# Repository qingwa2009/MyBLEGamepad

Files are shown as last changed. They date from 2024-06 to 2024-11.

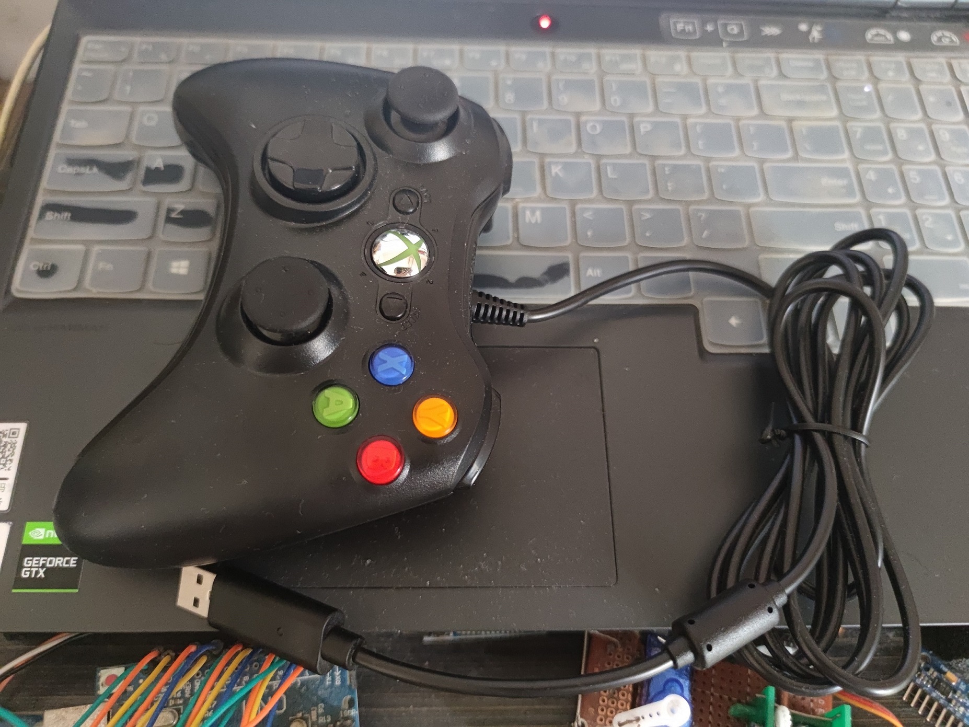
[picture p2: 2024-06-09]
pcb/00.jpg

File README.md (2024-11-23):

# MyBLEGamepad

## 功能介绍：

- #### 可以模拟xbox蓝牙手柄，SwitchPro蓝牙手柄，DualSense蓝牙手柄；

- #### 所有手柄都支持振动；
- #### switchPro手柄跟dualSense手柄支持陀螺仪体感操作；
- #### 除了switchPro手柄没有线性扳机，其他两个都有线性扳机；
- #### 支持绑定多台主机，3种模式可以同时绑定同一主机，使用时随意切换，无需重新绑定；
- #### 可以手动设置摇杆偏移，摇杆死区，陀螺仪自动校准；
- #### 正常刷新率在60Hz左右，可以开启高性能模式，刷新率可以达到120Hz；
- #### 支持win10平台：yuzu cemu dolphin模拟器跟steam都可以正常识别；
- #### 支持Android平台：我的小米10s装的DraStic模拟器也可以正常识别；

## 使用说明：

- ## 开关机及充电：

    - 开机：关机状态下，按一下xbox键，灯亮开机；
        * 开机蓝牙自动广播，LED灯有滚动效果，30秒没连接上自动关机；
        * 连接后，LED显示对应的手柄指示灯。

    - 关机：开机状态下，长按xbox键3秒，灯灭关机。

    - 充电：手柄插入usb电源自动充电，可以边充电边使用。
        * 关机状态下充电：LED显示当前电量，充电中会闪烁，充满时常亮。
        * 开机状态下充电：LED不会显示电量，只显示手柄模式，按一下xbox键切换到电量显示，3秒后自动切回显示当前手柄。

- ## 手柄模式：

    - 关机状态下按下：X + XBOX：
        * 进入xbox手柄模式，右上角LED指示灯亮起并播放广播灯效。

    - 关机状态下按下：A + XBOX：
        * 进入SwitchPro手柄模式，右下角LED指示灯亮起并播放广播灯效。

    - 关机状态下按下：Y + XBOX：
        * 进入DualSense手柄模式，左上角LED指示灯亮起并播放广播灯效。

    - 关机状态下按下：XBOX：
        * 进入上一次使用的的手柄模式，相应指示灯亮起。

    - 关机状态下按下：（L + A 或 X 或 Y + XBOX ）或（L + XBOX）：
        * 手柄会振动提示一下，进入对应手柄的高性能输出模式；
        * 高性能模式耗电增加，延迟降低到6~7ms左右。
    
    - 关机状态下按下：（START + A 或 X 或 Y + XBOX）或（START + XBOX）：
        * 清除蓝牙绑定，并进入对应手柄的模式。

    - 关机状态下按下：B + XBOX:
        * 进入校准模式，LED显示跑马灯效果。

    - 断电状态下：按下SELECT并用USB接通电脑：
        * 进入下载模式，该模式只再芯片首次烧录会用到。

- ## 校准模式：

        * 校准模式需要使用串口进行通信，所以需要用usb连接电脑；
        * 还有打开串口调试助手，串口波特率为115200；
        * 其他详细指令看串口输出的帮助说明。

- ## 绑定与删除绑定：

    * 3个手柄的名称分别为：MyXboxGamepad、MyProGamepad、MyDSGamepad；可以一起绑定。

    * 删除绑定：开机时，先按住start键，再按照上面提到的手柄模式开机，将自动删除对应手柄的绑定，
        * 此时手柄会处于广播状态。
        * （注意：Win10电脑绑定的信息不会自动删掉，需要手动删除，不然电脑会自动连接手柄，手柄自动断开连接，反复连接断开。）

- ## 该项目目录介绍：
    * 3D：原PCB描图，Solidworks文件，用处不大。
    * bootloader_components：bootloader代码
    * components：组件代码
    * main：该项目源码
    * pcb：
        * .epro文件：力创EDA专业版工程文件。
        * .pdf文件：eda导出的pdf，方便查阅。
    * prebuild：该项目预先编译好的bin文件，可以直接烧录，注意我用的芯片模组是：ESP32-S3-WROOM-1-N8R2，其他模组可能要自己修改编译一下了。

- ## 制作相关：
    * 我是直接网购的一个20块钱左右的有线带振动的xbox手柄来进行改装的。
    * 然后重新配着这个手柄，照着它的PCB轮廓重新描画，再在嘉立创免费打样。
    * pcb文件夹里面有该pcb相关的工程文件，pcb也调整到嘉立创可以免费打样的尺寸100*100mm；pcb文件夹里面的pdf有部分原件不焊的说明。
    * 原手柄的部分电子原件需要拆下来，省去另外购买：
        * 左右肩键：拆下来，引脚掰直，可以用。
        * 左右扳机电位计：拆下来，同样可以用。
         （注意：该手柄扳机键前段有一段很长的空行程，可以拿东西垫一下那个摇杆滑槽，有条件的可以直接在滑槽那里拧入一颗调节螺丝，这样可以直接调整扳机键的行程。）
        * 左右摇杆：它这个左右摇杆很辣鸡，线性非常差，我是另外花了2块钱买了2个摇杆替换的，线性度还行，就是尺寸有点大，所有PCB里面摇杆的孔位我是改过的。其实用回原来的摇杆然后替换掉里面的电位计，也是可以的，PCB的孔位就要改一下了。
        
        * (我做好后发现：左摇杆有点偏左下，但是都做好了我就懒得重做了，所以PCB左摇杆的位置你们自己动手量一下按实际调整吧，右摇杆也是（~_~）。)

        * 振动马达：拆下来。
    * 其他那些电容电阻的封装我都是看我有什么就用什么的，没什么讲究，盖上外壳可能会跟背盖上的筋有点干涉，要削一下。
    * 充电管理芯片：TP4056
    * 稳压芯片：AP2112K-3.3TR
    * 陀螺仪：MPU6050
    * 磁力计：QMC5883L，我用电烙铁焊了两个钟都焊不上，放弃，也用不上，有也只是多个点缀，目前那些带体感看的手柄它们传输的数据也没磁力计。
    * 电池：手柄内部空间我测量了下，估计最多可以塞个300~400mAh的电池，太小了，ESP32耗电其实也挺高的，正常可以到70~80mA，两个振动马达1个100mA左右，玩不了多久就没电，所以我是选择将电池贴到手柄壳外面，想贴多大贴多大，我买了个800mAh，感觉还是小了点，可以搞个1600mAh的。
    * 那些硅胶键的焊盘我是加了些焊锡的，不然太平了，接触不太好，但是也别加太厚，太厚按键按不下去，没手感。

- ## 烧录相关：
    * 使用idf烧录：
        * 注意idf用的5.1.1版本，其他版本编译运行可能有问题。
        * 对于安装了Espressif开发工具的，可以直接用idf.py自行进行编译烧录。
        * 按住手柄SELECT按键，再用USB插入电脑，自动进入下载模式，然后按正常idf编译烧录方式烧录了。
    * 使用烧录工具烧录：
        * https://www.espressif.com.cn/zh-hans/support/download/other-tools
        * 去上面的路径下载Flash下载工具。
        * 打开烧录工具，ChipType选ESP32-S3，WorkMode选Develop，LoadMode选UART。
        * 直接使用该项目编译好的bin文件，在prebuild目录下，填入路径、偏移地址、打勾：
            * bootloader.bin 偏移地址 0x0
            * partition-table.bin 偏移地址 0x8000
            * main.bin 偏移地址 0x10000
        * SPI Speed：80M
        * SPI MODE：DIO
        * COM：选你的串口号，如：COM11
        * BAUD：115200
        * 最后点start，开始烧录，烧完拔掉USB重新上电就可以了。

- ## 视频演示：
    * https://www.bilibili.com/video/BV1YaG6e4Eqe

- ## 主要材料及价格：
    |   材料    |   数量    |   价格￥    |
    |:-:|:-:|-:|
    |山寨xbox有线手柄带振动|1|20.06|
    |ESP32s3-WROOM-1N8R2|1|17.80|
    |800mAh软包锂电池|1|10.60|
    |TP4056|1|0.38|
    |MPU6050|1|4.50|
    |AP2112K-3.3TR|1|0.35|
    |Type-c|1|0.32|
    |1N5819W|19|1.34|
    |SI2305|2|0.06|
    |SI2302|3|0.06|
    |LED|4|0.04|
    |摇杆|2|1.95|
    |PCB嘉立创白嫖|1|0.00|
    |100k电阻|8||
    |10k电阻|5||
    |5.1k电阻|2||
    |1k电阻|2||
    |2欧电阻(可以尝试去掉)|2||
    |0.5欧电阻|1||
    |2.2nF电容|1||
    |10nF电容|1||
    |100nF电容|4||
    |0.2uF电容|2||
    |1uF电容|3||
    |10uF电容|6||
    |22uF电容|1||

总计60块钱左右。

- ## 可能潜在的问题：

    * #### 所有手柄模式都没有在对应的主机测试过，所以不保证可以在主机运行。

- ## 参考资料：
    * https://github.com/dekuNukem/Nintendo_Switch_Reverse_Engineering.git
    * https://github.com/mumumusuc/libjoycon.git
    * https://github.com/EasyConNS/BlueCon-esp32.git
    * https://controllers.fandom.com/wiki/Sony_DualSense
    * https://github.com/libsdl-org/SDL.git

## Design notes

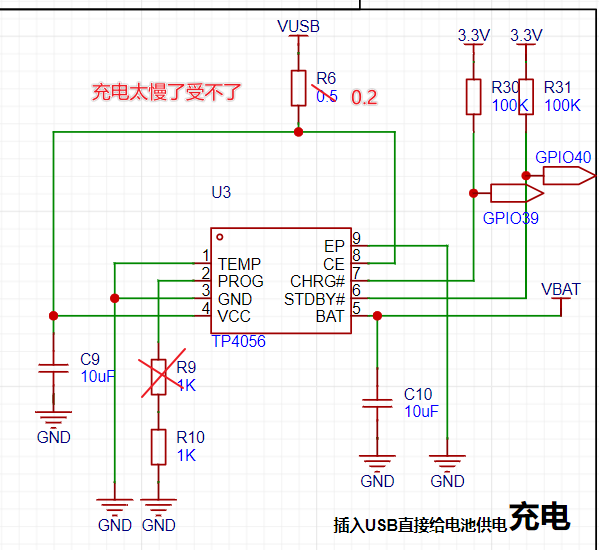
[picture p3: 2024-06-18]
pcb/充电部分电路修改.png

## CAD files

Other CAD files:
3D/零件1.SLDPRT
3D/零件1.DXF
3D/零件1.SLDDRW

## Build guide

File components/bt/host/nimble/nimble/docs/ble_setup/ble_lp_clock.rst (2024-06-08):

Configure clock for controller
------------------------------

The NimBLE stack uses OS cputime for scheduling various events inside
controller. Since the code of controller is optimized to work with 32768
Hz clock, the OS cputime has to be configured accordingly.

To make things easier, controller package (``net/nimble/controller``)
defines new system configuration setting ``BLE_LP_CLOCK`` as sets it to
``1`` so other packages can be configured if necessary. The next section
describes configuration required for controller to work properly.

System configuration
~~~~~~~~~~~~~~~~~~~~

**Note:** All BSPs based on nRF5x have below settings automatically
applied when ``BLE_LP_CLOCK`` is set, there is no need to configure this
in application.

The following things need to be configured for NimBLE controller to work
properly:

-  OS cputime frequency shall be set to ``32768``
-  OS cputime timer source shall be set to 32768 Hz clock source
-  Default 1 MHz clock source can be disabled if not used by application
-  32768 Hz clock source shall be enabled
-  Crystal settling time shall be set to non-zero value (see below)

For example, on nRF52 platform timer 5 can be used as source for 32768
Hz clock. Also, timer 0 can be disabled since this is the default source
for OS cputime clock and is no longer used. The configuration will look
as below:

::

    syscfg.vals:
        OS_CPUTIME_FREQ: 32768
        OS_CPUTIME_TIMER_NUM: 5
        TIMER_0: 0
        TIMER_5: 1
        BLE_XTAL_SETTLE_TIME: 1500

On nRF51 platform the only difference is to use timer 3 instead of timer
5.

On platforms without 32768 Hz crystal available it usually can be
synthesized by setting ``XTAL_32768_SYNTH`` to ``1`` - this is also
already configured in existing BSPs.

Crystal settle time configuration
~~~~~~~~~~~~~~~~~~~~~~~~~~~~~~~~~

The configuration variable ``BLE_XTAL_SETTLE_TIME`` is used by the
controller to turn on the necessary clock source(s) for the radio and
associated peripherals prior to Bluetooth events (advertising, scanning,
connections, etc). For the nRF5x platforms, the HFXO needs to be turned
on prior to using the radio and the ``BLE_XTAL_SETTLE_TIME`` must be set
to accommodate this time. The amount of time required is board
dependent, so users must characterize their hardware and set
``BLE_XTAL_SETTLE_TIME`` accordingly. The current value of 1500
microseconds is a fairly long time and was intended to work for most, if
not all, platforms.

Note that changing this time will impact battery life with the amount
depending on the application. The HFXO draws a fairly large amount of
current when running so keeping this time as small as possible will
reduce overall current drain.

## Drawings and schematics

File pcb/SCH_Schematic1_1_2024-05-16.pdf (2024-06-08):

IO0 27 IO35 28 IO36 29 IO37 30 IO38 31 IO39 32 IO40 33 IO41 34 IO42 35 RXD0 36 TXD0 37 IO2 38 IO1 39 GND 40

## 这个重置键用不上不焊

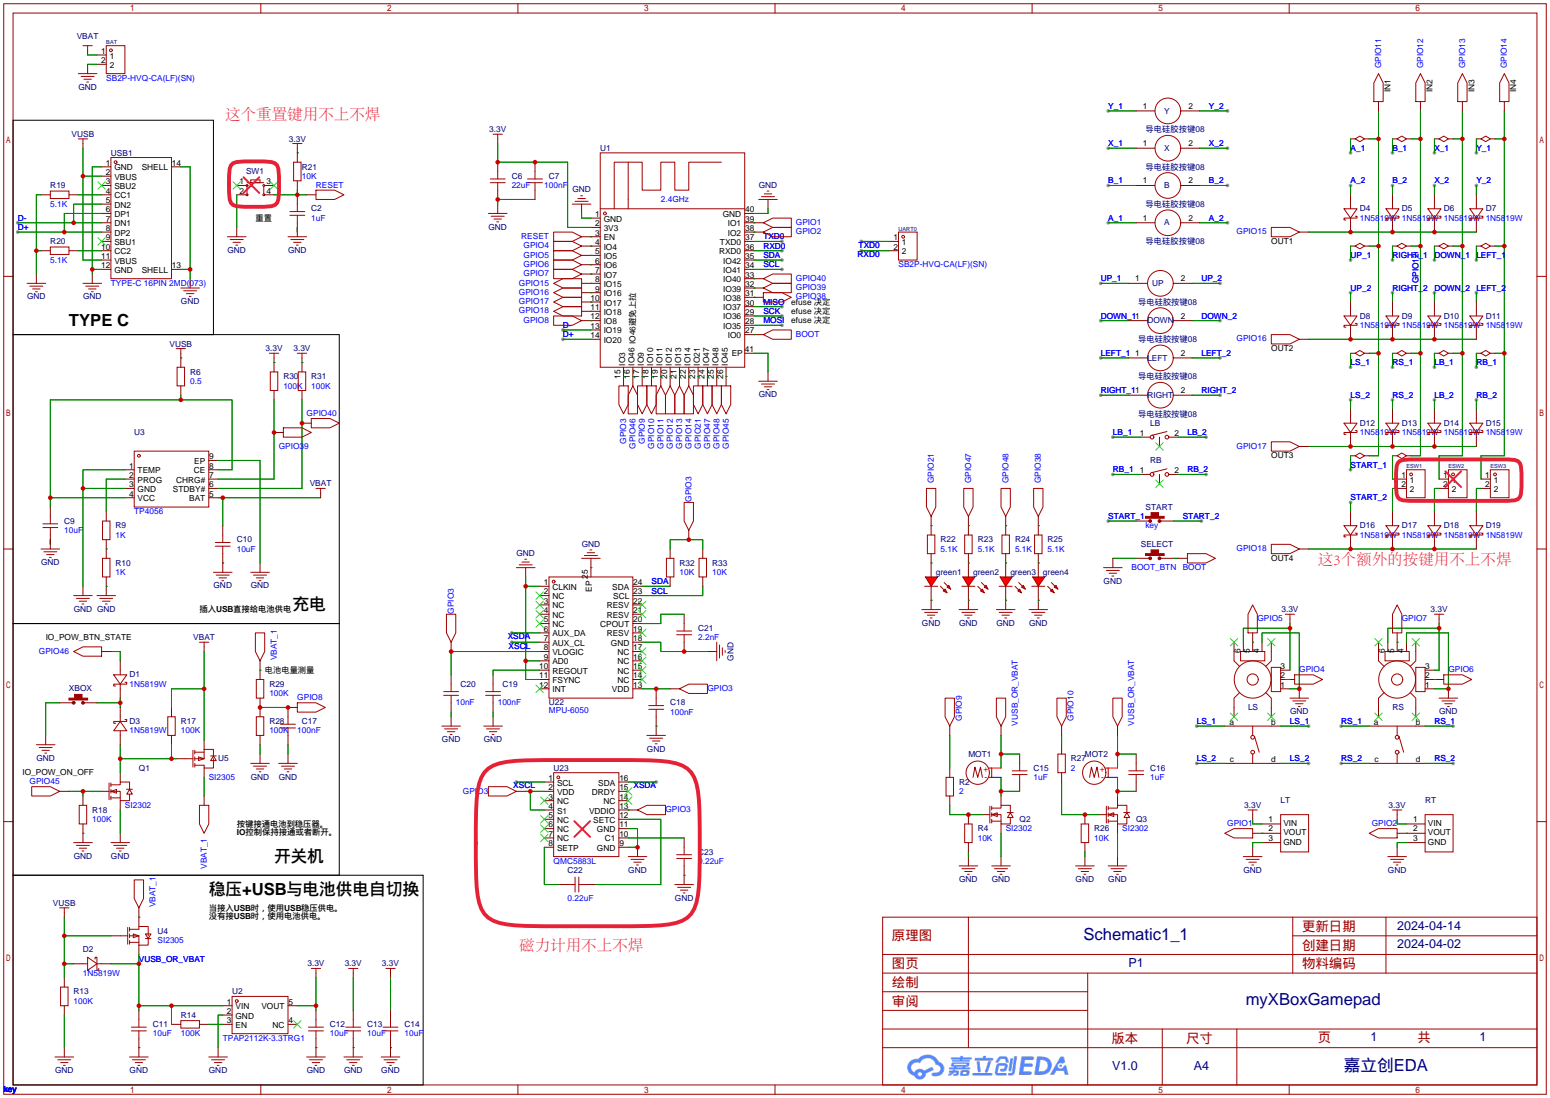
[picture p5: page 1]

C1 10 GND 11 SETC 12 VDDIO 13 NC 14 DRDY 15 SDA 16

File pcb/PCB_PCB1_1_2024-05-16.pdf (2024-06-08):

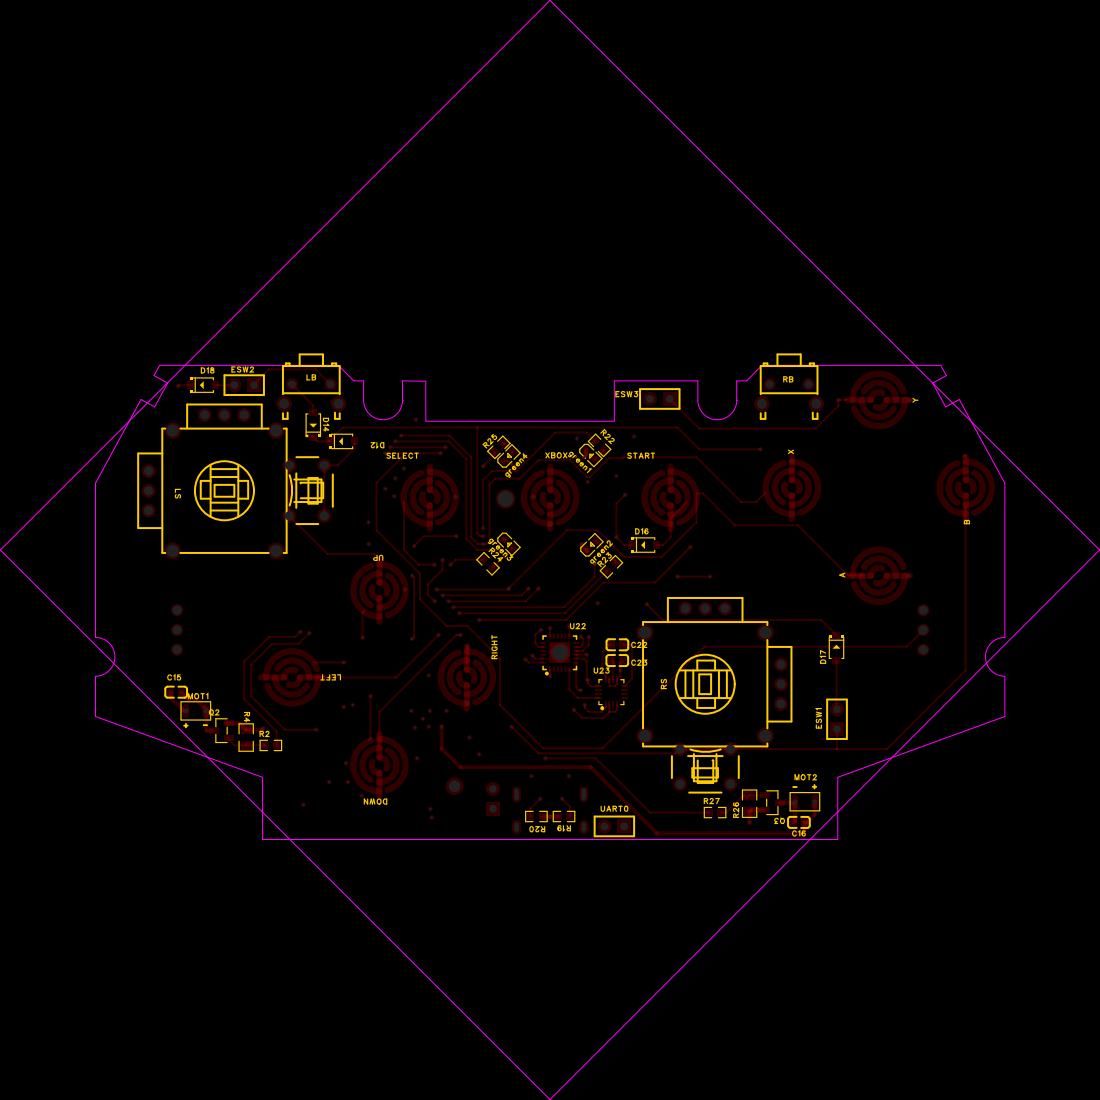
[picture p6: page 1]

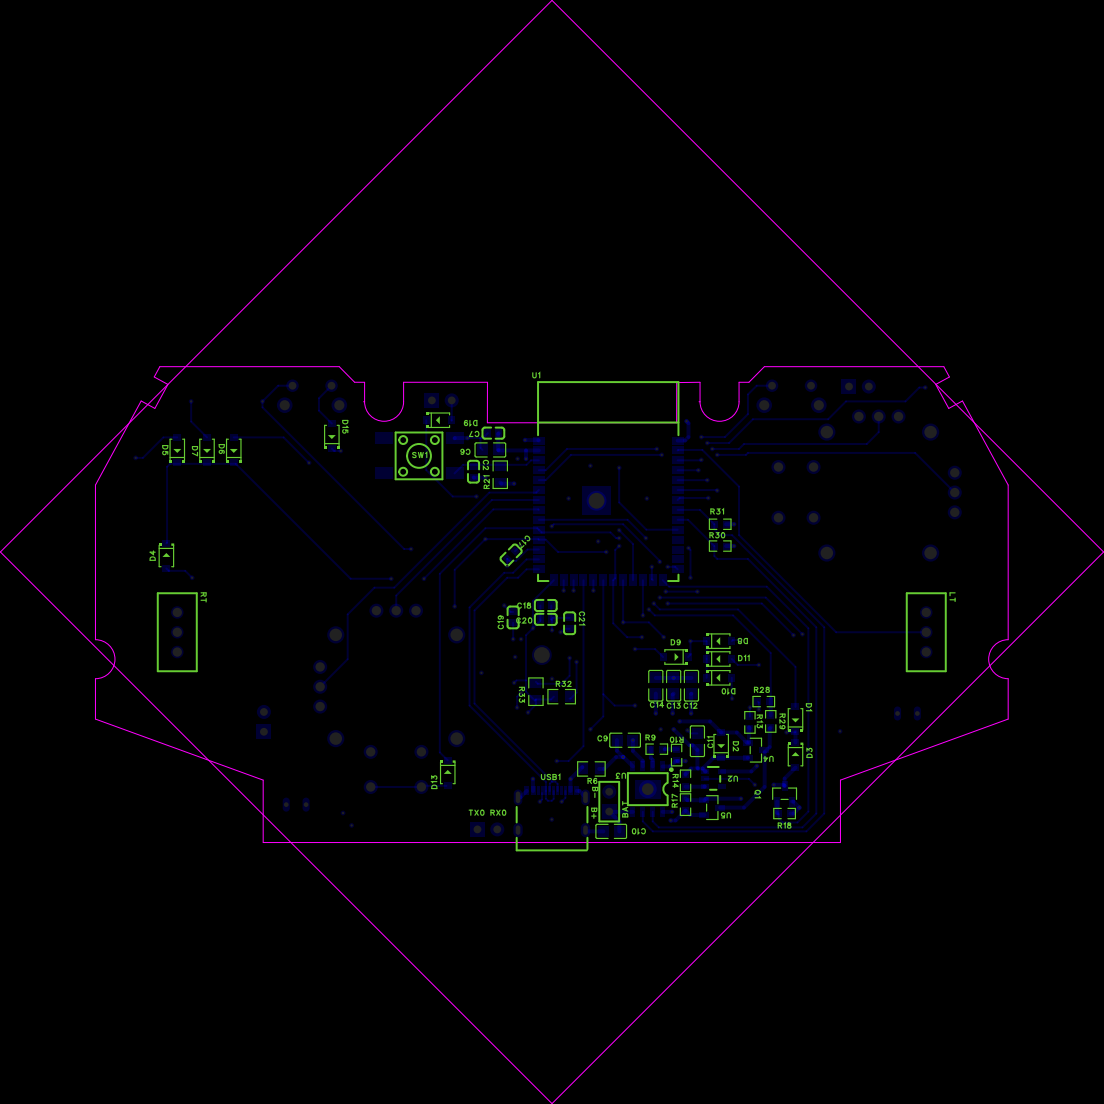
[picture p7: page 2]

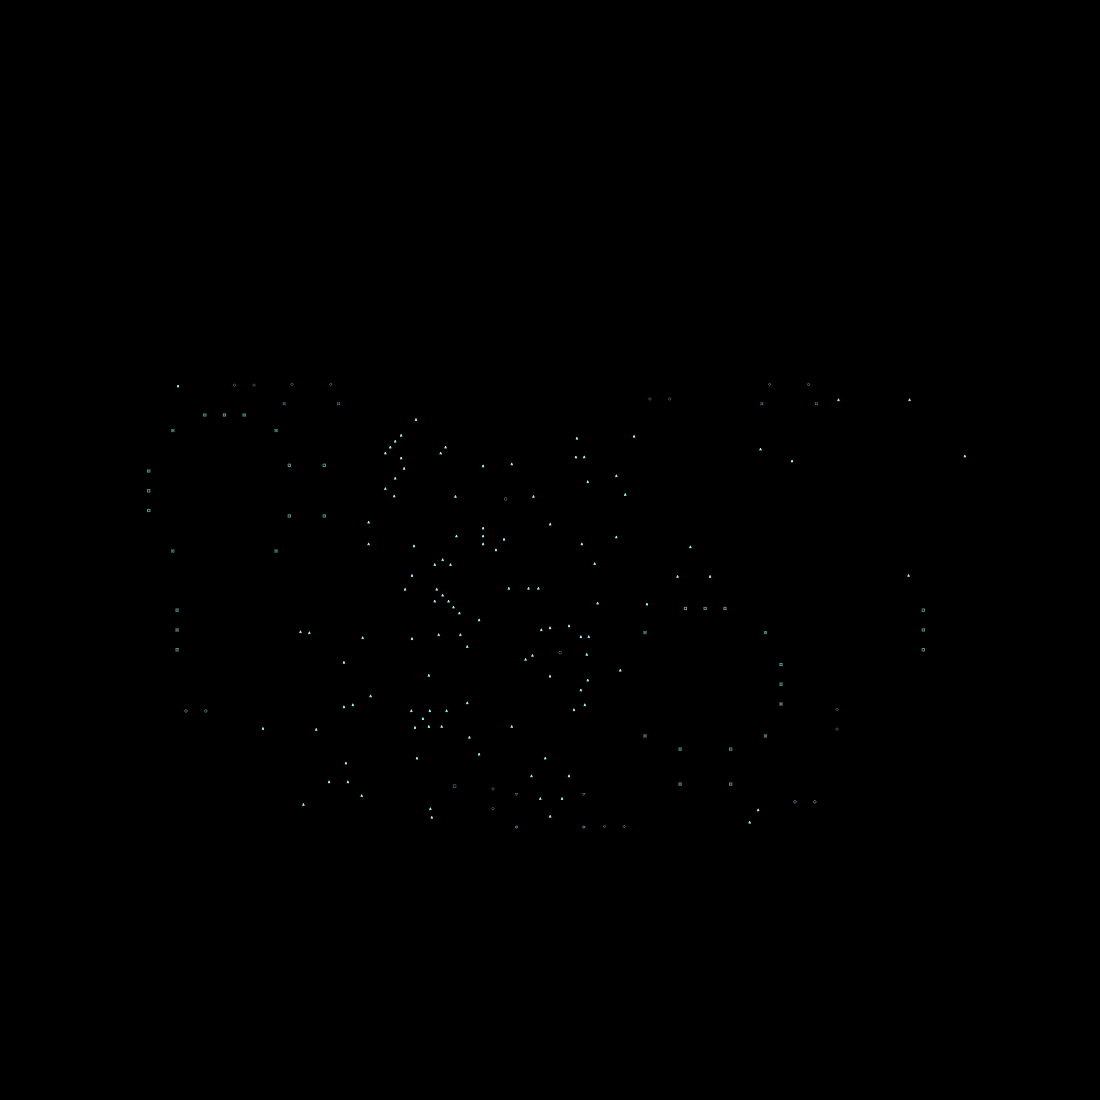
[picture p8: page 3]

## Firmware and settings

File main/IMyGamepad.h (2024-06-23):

#ifndef _I_MY_GAMEPAD_H_
#define _I_MY_GAMEPAD_H_
#include "pcbConfig.h"
#include "NimBLEHIDDevice.h"

#define MAX_ADVERTISING_TIME_MS 0 //0 for infinite
// Minimum connection interval (units of 1.25ms) if automatic parameter update request is enabled
#define DEFAULT_DESIRED_MIN_CONN_INTERVAL 12
// Maximum connection interval (units of 1.25ms) if automatic parameter update request is enabled
#define DEFAULT_DESIRED_MAX_CONN_INTERVAL 16
// Slave latency to use if automatic parameter update request is enabled
// 0 ~ ((connSupervisionTimeout / (connIntervalMax*2)) -1).
#define DEFAULT_DESIRED_SLAVE_LATENCY 0
// Supervision timeout value (units of 10ms) if automatic parameter update request is enabled
#define DEFAULT_SUPERVISION_TIMEOUT 300

#define DEFAULT_SEND_PERIOD_MS 15 //发送间隔ms

#define BOOST_DESIRED_MIN_CONN_INTERVAL 6
#define BOOST_DESIRED_MAX_CONN_INTERVAL 6
#define BOOST_DESIRED_SLAVE_LATENCY 0
#define BOOST_DESIRED_SLAVE_LATENCY 0
#define BOOST_SEND_PERIOD_MS 7 //发送间隔ms

#define BUILD_UINT16(loByte, hiByte) \
    ((uint16_t)(((loByte)&0x00FF) + (((hiByte)&0x00FF) << 8)))

#define HI_UINT16(a) (((a) >> 8) & 0xFF)
#define LO_UINT16(a) ((a)&0xFF)

class IMyGamepad : public NimBLEServerCallbacks
{
private:
    NimBLEServer *pServer;
    void onConnect(NimBLEServer *pServer, NimBLEConnInfo &connInfo) override;
    void onDisconnect(NimBLEServer *pServer, NimBLEConnInfo &connInfo, int reason) override;
    void onMTUChange(uint16_t MTU, NimBLEConnInfo &connInfo) override;
    uint32_t onPassKeyRequest() override;
    void onAuthenticationComplete(NimBLEConnInfo &connInfo) override;
    bool onConfirmPIN(uint32_t pin) override;

protected:
    NimBLEHIDDevice *pHidDev;
    NimBLECharacteristic *_battChara;
    bool isKeyStateChange(KeyMatrix_t *keys, uint8_t btnXbox, uint8_t btnSelect, int x, int y, int z, int rz, int lt, int rt);
    //0~8 0没输入
    int dirKey2DPadValue(int up, int right, int down, int left);
    int dead_x, dead_y, dead_z, dead_rz;
    int SEND_PERIOD_MS = DEFAULT_SEND_PERIOD_MS;
    int DESIRED_MIN_CONN_INTERVAL = DEFAULT_DESIRED_MIN_CONN_INTERVAL;
    int DESIRED_MAX_CONN_INTERVAL = DEFAULT_DESIRED_MAX_CONN_INTERVAL;
    int DESIRED_SLAVE_LATENCY = DEFAULT_DESIRED_SLAVE_LATENCY;

public:
    IMyGamepad(const std::string &deviceName);
    ~IMyGamepad();
    /*x,y,z,rz,lt,rt: 0~100*/
    virtual void update(uint32_t dt, KeyMatrix_t *keys, uint8_t btnXbox, uint8_t btnSelect, int x, int y, int z, int rz, int lt, int rt) = 0;
    void start(bool powBoostMode = false);
    void stop();
    size_t getConnectedCount();
    void notifyBattLevel(uint8_t level);
    void clearBond();
    void setDeadZone(int deadx, int deady, int deadz, int deadrz);
};

uint8_t getRptID(NimBLECharacteristic *pCharacteristic);

#ifdef __cplusplus
extern "C"
{
#endif
#ifdef __cplusplus
}
#endif

#endif

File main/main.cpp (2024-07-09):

#include <stdio.h>
#include "freertos/FreeRTOS.h"
#include "freertos/task.h"
#include "esp_log.h"
#include "driver/gpio.h"
#include "esp_timer.h"
#include "driver/dedic_gpio.h"
#include "esp_adc/adc_oneshot.h"
#include "esp_adc/adc_cali.h"
#include "esp_adc/adc_cali_scheme.h"
#include "pcbConfig.h"
#include "MyMeanFilter.h"
#include "MyKeypadMatrix.h"
#include "driver/ledc.h"
#include "NimBLEDevice.h"
#include "NimBLEHIDDevice.h"
#include "ble_uuid.h"
#include "driver/i2c.h"
#include "MPU6050.h"
#include "helper.h"
#include "esp_sleep.h"
#include "esp_pm.h"
#include "nvs_flash.h"
#include "esp_console.h"
#include "esp_task_wdt.h"
#include "esp_mac.h"

// #include "MPU6050_6Axis_MotionApps612.h"

#include "XboxOneGamepad.h"
#include "SwitchProController.h"
#include "DualSenseController.h"

#define ENABLE_LIGHT_SLEEP true

#define TIME_HOLDE_POW_OFF_MS 3000
#define BTN_PIN_LEVEL_STABLE_DELAY_NOP_COUNT 1 //按键电平切换稳定所需的空语句计数

#define DEFAULT_ADC_UNIT_ID ADC_UNIT_1
#define DEFAULT_ADC_ATTEN_DB ADC_ATTEN_DB_11
#define DEFAULT_ADC_BITWIDTH ADC_BITWIDTH_12

#define DEFAULT_SCAN_TIME_OUT_MS 30000 //扫描30s未连接自动关机

#define DELAY(x) vTaskDelay((x) / portTICK_PERIOD_MS)

static const char *TAG = "main";

static int isPowOnByPushBtn = 0;
static int _isPowOff = 0;
static volatile Enum_Gamepad_Type _gamepadType = GAMEPAD_TYPE_XBOX;
static volatile int _isScanning = 1;
static IMyGamepad *pGamepad = nullptr;

static const char *NVS_XBOX_BOND = "xbox_bond";
static const char *NVS_PRO_BOND = "pro_bond";
static const char *NVS_DS_BOND = "ds_bond";
static const char *mynvs = "mynvs";
static const char *mynvsKeyGPT = "gpt";
static const char *calinvs = "cali";
static const char *name_xbox = "MyXboxGamepad";
static const char *name_pro = "MyProGamepad";
static const char *name_ds = "MyDSGamepad";

static const char *cmdCaliMPU = "/m";
static const char *cmdCaliSticks = "/c";
static const char *cmdSaveSticks = "/s";
static const char *cmdSaveDeadZone = "/d";

static int16_t min_x, mid_x, max_x, min_y, mid_y, max_y, min_z, mid_z, max_z, min_rz, mid_rz, max_rz;
static int16_t dead_x, dead_y, dead_z, dead_rz;
//直接改存放绑定信息下nvs名称空间，实现多重绑定。
#include "../components/bt/nimble_nvs_namespace_variable.h"
const char *NIMBLE_NVS_NAMESPACE;

#ifdef __cplusplus
extern "C"
{
#endif
    void app_main(void);
#ifdef __cplusplus
}
#endif

/**
 * 接通电池。
*/
void connectBattery()
{
    //在bootloader已经做了输入输出的设置
    gpio_set_level(PIN_SWITCH_ON_OFF, 1);
}
void disconnectBattery()
{
    gpio_set_level(PIN_SWITCH_ON_OFF, 0);
}

int isBatteryConnected()
{
    //在bootloader已经做了输入输出的设置
    return gpio_get_level(PIN_SWITCH_ON_OFF);
}

//0b0000~0b1111
void setLEDState(uint8_t state)
{

    gpio_set_level(PIN_LED_1, state & 0b0001);
    gpio_set_level(PIN_LED_2, state & 0b0010);
    gpio_set_level(PIN_LED_3, state & 0b0100);
    gpio_set_level(PIN_LED_4, state & 0b1000);
}

void reset(bool byTWDT)
{

    //取消掉IO的保持功能，不然软重置也重置不了
    // gpio_hold_dis(PIN_LED_1);
    // gpio_hold_dis(PIN_LED_2);
    // gpio_hold_dis(PIN_LED_3);
    // gpio_hold_dis(PIN_LED_4);
    // gpio_hold_dis(PIN_I2C_VCC);
    // gpio_hold_dis(PIN_SWITCH_ON_OFF);
    if (byTWDT)
        esp_system_abort("reset by watch dog!!!");
    else
        esp_system_abort("reset by press xbox btn!!!");
}

void powOn()
{
    _isPowOff = 0;
    connectBattery();
}
/**
 * 关机
*/
void powOff()
{
    _isPowOff = 1;
    pGamepad->stop();
    setLEDState(0b0000);
    esp_wifi_bt_power_domain_off();
    disconnectBattery();
}

//xbox 按键还要负责开关机，所以按下时不返回按下，松开时才返回按下，下一帧返回松开
int checkXboxBtn(uint32_t dt)
{
    static int preXboxBtnState = 0;
    static uint32_t t = 0;
    static int enableXboxBtnAsPowBtn = 0; //按住开机时，关闭xbox按键的关机功能

    int isXboxBtnDown = !gpio_get_level(PIN_BTN_XBOX);
    if (!_isPowOff)
    {
        if (isXboxBtnDown)
        {
            if (enableXboxBtnAsPowBtn)
                t += dt;
            //长按超时
            if ((t) > (TIME_HOLDE_POW_OFF_MS))
            {
                powOff();
                return 0;
            }
            preXboxBtnState = 1;
            return 0;
        }
        else
        {
            enableXboxBtnAsPowBtn = 1;
            t = 0;
            if (preXboxBtnState > 0)
            {
                preXboxBtnState = 0;
                return 1;
            }
            else
            {
                preXboxBtnState = 0;
                return 0;
            }
        }
    }
    else
    {
        //长按关机，松手后。
        if (!isXboxBtnDown)
        {
            //重启
            reset(false);
        }
        preXboxBtnState = 0;
        return 0;
    }
}

adc_oneshot_unit_handle_t adcHandle = NULL;
adc_cali_handle_t adcCaliHandle = NULL;
void _initADCHandle()
{
    if (adcHandle != NULL)
        return;
    adc_oneshot_unit_init_cfg_t initCfg = {
        .unit_id = DEFAULT_ADC_UNIT_ID,
        .clk_src = (adc_oneshot_clk_src_t)0,
        .ulp_mode = ADC_ULP_MODE_DISABLE,
    };
    ESP_ERROR_CHECK(adc_oneshot_new_unit(&initCfg, &adcHandle));
}

void initADCSticks()
{
    _initADCHandle();
    adc_oneshot_chan_cfg_t chanCfg = {
        .atten = DEFAULT_ADC_ATTEN_DB,
        .bitwidth = DEFAULT_ADC_BITWIDTH,
    };
    ESP_ERROR_CHECK(adc_oneshot_config_channel(adcHandle, PIN_ADC_X, &chanCfg));
    ESP_ERROR_CHECK(adc_oneshot_config_channel(adcHandle, PIN_ADC_Y, &chanCfg));
    ESP_ERROR_CHECK(adc_oneshot_config_channel(adcHandle, PIN_ADC_Z, &chanCfg));
    ESP_ERROR_CHECK(adc_oneshot_config_channel(adcHandle, PIN_ADC_RZ, &chanCfg));
    ESP_ERROR_CHECK(adc_oneshot_config_channel(adcHandle, PIN_ADC_LT, &chanCfg));
    ESP_ERROR_CHECK(adc_oneshot_config_channel(adcHandle, PIN_ADC_RT, &chanCfg));
}

int getADCValue(adc_channel_t channel)
{
    int v = 0;
    ESP_ERROR_CHECK(adc_oneshot_read(adcHandle, channel, &v));
    return v;
}

int getADCValueAfterCali(adc_channel_t channel)
{
    int vRaw, vOut;
    ESP_ERROR_CHECK(adc_oneshot_read(adcHandle, channel, &vRaw));
    ESP_ERROR_CHECK(adc_cali_raw_to_voltage(adcCaliHandle, vRaw, &vOut));
    // ESP_LOGI(TAG, "raw = %d v= %dmv \r\n", vRaw, vOut);
    return vOut;
}

void initMotor()
{
    gpio_reset_pin(PIN_MOTOR_L);
    gpio_reset_pin(PIN_MOTOR_R);

    ledc_timer_config_t ledcTCfg = {
        .speed_mode = LEDC_MOTOR_SPEED_MODE,
        .duty_resolution = LEDC_TIMER_12_BIT,
        .timer_num = LEDC_MOTOR_L_TIMER,
        .freq_hz = LEDC_MOTOR_FRQ_DEFAULT,
        .clk_cfg = LEDC_AUTO_CLK,
    };
    ESP_ERROR_CHECK(ledc_timer_config(&ledcTCfg));

    ledc_channel_config_t ledcCCfg = {
        .gpio_num = PIN_MOTOR_L,
        .speed_mode = LEDC_MOTOR_SPEED_MODE,
        .channel = LEDC_MOTOR_L_CHANNEL,
        .intr_type = LEDC_INTR_DISABLE,
        .timer_sel = LEDC_MOTOR_L_TIMER,
        .duty = 0,
        .hpoint = 0,
        .flags = {.output_invert = 0},
    };
    ESP_ERROR_CHECK(ledc_channel_config(&ledcCCfg));

    ledcTCfg.timer_num = LEDC_MOTOR_R_TIMER;
    ESP_ERROR_CHECK(ledc_timer_config(&ledcTCfg));
    ledcCCfg.gpio_num = PIN_MOTOR_R;
    ledcCCfg.channel = LEDC_MOTOR_R_CHANNEL;
    ledcCCfg.timer_sel = LEDC_MOTOR_R_TIMER;
    ESP_ERROR_CHECK(ledc_channel_config(&ledcCCfg));
}

void setMotorFreq(uint16_t lFreq, uint16_t rFreq)
{
    ledc_set_freq(LEDC_MOTOR_SPEED_MODE, LEDC_MOTOR_L_TIMER, lFreq);
    ledc_set_freq(LEDC_MOTOR_SPEED_MODE, LEDC_MOTOR_R_TIMER, rFreq);
}
//0~100
void setMotorLevel(uint16_t lMotor, uint16_t rMotor)
{
    if (lMotor > 100)
        lMotor = 100;
    if (rMotor > 100)
        rMotor = 100;
    ledc_set_duty(LEDC_MOTOR_SPEED_MODE, LEDC_MOTOR_L_CHANNEL, lMotor * 40);
    ledc_update_duty(LEDC_MOTOR_SPEED_MODE, LEDC_MOTOR_L_CHANNEL);
    ledc_set_duty(LEDC_MOTOR_SPEED_MODE, LEDC_MOTOR_R_CHANNEL, rMotor * 40);
    ledc_update_duty(LEDC_MOTOR_SPEED_MODE, LEDC_MOTOR_R_CHANNEL);

    // ESP_LOGI(TAG, "LMotor: %d, RMotr: %d", lMotor, rMotor);
}
void getMotorLevel(uint16_t *lMotor, uint16_t *rMotor)
{
    *lMotor = ledc_get_duty(LEDC_MOTOR_SPEED_MODE, LEDC_MOTOR_L_CHANNEL) / 40;
    *rMotor = ledc_get_duty(LEDC_MOTOR_SPEED_MODE, LEDC_MOTOR_R_CHANNEL) / 40;
}

void initGamepadBLE(bool clearBond, bool powBoostMode)
{
    //改BLE地址，以区分不同手柄（注意这里的地址是最低字节在最高地址）
    uint8_t mac[6];
    esp_read_mac(mac, ESP_MAC_BT);
    ESP_LOGI(TAG, "Base BLE Public Addr: %02x:%02x:%02x:%02x:%02x:%02x", mac[0], mac[1], mac[2], mac[3], mac[4], mac[5]);
    mac[1] += _gamepadType;
    esp_iface_mac_addr_set(mac, ESP_MAC_BT);
    ESP_LOGI(TAG, "Set BLE Public Addr: %02x:%02x:%02x:%02x:%02x:%02x", mac[0], mac[1], mac[2], mac[3], mac[4], mac[5]);

    switch (_gamepadType)
    {
    case GAMEPAD_TYPE_SWITCH_PRO:
        //直接改存放绑定信息下nvs名称空间，实现多重绑定。
        NIMBLE_NVS_NAMESPACE = NVS_PRO_BOND;
        pGamepad = new SwitchProController(name_pro);
        break;
    case GAMEPAD_TYPE_DS:
        //直接改存放绑定信息下nvs名称空间，实现多重绑定。
        NIMBLE_NVS_NAMESPACE = NVS_DS_BOND;
        pGamepad = new DualSenseController(name_ds);
        break;
    default:
        //直接改存放绑定信息下nvs名称空间，实现多重绑定。
        NIMBLE_NVS_NAMESPACE = NVS_XBOX_BOND;
        pGamepad = new XboxOneGamepad(name_xbox);
        break;
    }
    if (clearBond)
    {
        pGamepad->clearBond();
    }
    pGamepad->setDeadZone(dead_x, dead_y, dead_z, dead_rz);
    pGamepad->start(powBoostMode);
}

void normalizeJoyStrickValue(int *_x, int *_y, int *_z, int *_rz)
{
    int x = *_x;
    int y = *_y;
    int z = *_z;
    int rz = *_rz;
    x = 4095 - x;
    z = 4095 - z;
    rz = 4095 - rz;
    x = (int)((x * 100L) / 4095);
    y = (int)((y * 100L) / 4095);
    z = (int)((z * 100L) / 4095);
    rz = (int)((rz * 100L) / 4095);

    // ESP_LOGI(TAG, ",x=%d,y=%d,z=%d,rz=%d", x, y, z, rz);

    x = (x == mid_x) ? 50 : ((x < mid_x) ? map(x, min_x, mid_x, 0, 50) : map(x, mid_x, max_x, 50, 100));
    y = (y == mid_y) ? 50 : ((y < mid_y) ? map(y, min_y, mid_y, 0, 50) : map(y, mid_y, max_y, 50, 100));
    z = (z == mid_z) ? 50 : ((z < mid_z) ? map(z, min_z, mid_z, 0, 50) : map(z, mid_z, max_z, 50, 100));
    rz = (rz == mid_rz) ? 50 : ((rz < mid_rz) ? map(rz, min_rz, mid_rz, 0, 50) : map(rz, mid_rz, max_rz, 50, 100));

    if (x < 0)
        x = 0;
    else if (x > 100)
        x = 100;
    if (y < 0)
        y = 0;
    else if (y > 100)
        y = 100;
    if (z < 0)
        z = 0;
    else if (z > 100)
        z = 100;
    if (rz < 0)
        rz = 0;
    else if (rz > 100)
        rz = 100;

    *_x = x;
    *_y = y;
    *_z = z;
    *_rz = rz;
}

void normalizeTriggerValue(int *_lt, int *_rt)
{
    int lt = *_lt;
    int rt = *_rt;
    lt /= 40;
    rt /= 40;
    if (lt > 100)
        lt = 100;
    else if (lt < 0)
        lt = 0;
    if (rt > 100)
        rt = 100;
    else if (rt < 0)
        rt = 0;
    *_lt = lt;
    *_rt = rt;
}

MPU6050 mpu;
static int isIMUEnabled = false;
void initI2C()
{
    i2c_config_t cfg;
    cfg.mode = I2C_MODE_MASTER;
    cfg.sda_io_num = PIN_I2C_SDA;
    cfg.scl_io_num = PIN_I2C_SCL;
    cfg.sda_pullup_en = 0;
    cfg.scl_pullup_en = 0;
    cfg.master.clk_speed = 400000;
    cfg.clk_flags = I2C_SCLK_SRC_FLAG_FOR_NOMAL;
    i2c_param_config(I2C_NUM_0, &cfg);
    ESP_ERROR_CHECK(i2c_driver_install(I2C_NUM_0, cfg.mode, 0, 0, 0));
}
void saveDeadZone(int16_t deadx, int16_t deady, int16_t deadz, int16_t deadrz)
{
    nvs_handle_t h;
    nvs_open(calinvs, NVS_READWRITE, &h);
    nvs_set_i16(h, "deadx", deadx);
    nvs_set_i16(h, "deady", deady);
    nvs_set_i16(h, "deadz", deadz);
    nvs_set_i16(h, "deadrz", deadrz);
    nvs_commit(h);
    nvs_close(h);
}
void loadDeadZone(int16_t *deadx, int16_t *deady, int16_t *deadz, int16_t *deadrz)
{
    nvs_handle_t h;
    nvs_open(calinvs, NVS_READWRITE, &h);
    nvs_get_i16(h, "deadx", deadx);
    nvs_get_i16(h, "deady", deady);
    nvs_get_i16(h, "deadz", deadz);
    nvs_get_i16(h, "deadrz", deadrz);
    nvs_close(h);
}
void saveSticksOffset(int16_t minx, int16_t midx, int16_t maxx, int16_t miny, int16_t midy, int16_t maxy, int16_t minz, int16_t midz, int16_t maxz, int16_t minrz, int16_t midrz, int16_t maxrz)
{
    nvs_handle_t h;
    nvs_open(calinvs, NVS_READWRITE, &h);
    nvs_set_i16(h, "minx", minx);
    nvs_set_i16(h, "midx", midx);
    nvs_set_i16(h, "maxx", maxx);
    nvs_set_i16(h, "miny", miny);
    nvs_set_i16(h, "midy", midy);
    nvs_set_i16(h, "maxy", maxy);
    nvs_set_i16(h, "minz", minz);
    nvs_set_i16(h, "midz", midz);
    nvs_set_i16(h, "maxz", maxz);
    nvs_set_i16(h, "minrz", minrz);
    nvs_set_i16(h, "midrz", midrz);
    nvs_set_i16(h, "maxrz", maxrz);
    nvs_commit(h);
    nvs_close(h);
}
void loadSticksOffset(int16_t *minx, int16_t *midx, int16_t *maxx, int16_t *miny, int16_t *midy, int16_t *maxy, int16_t *minz, int16_t *midz, int16_t *maxz, int16_t *minrz, int16_t *midrz, int16_t *maxrz)
{
    nvs_handle_t h;
    nvs_open(calinvs, NVS_READWRITE, &h);
    nvs_get_i16(h, "minx", minx);
    nvs_get_i16(h, "midx", midx);
    nvs_get_i16(h, "maxx", maxx);
    nvs_get_i16(h, "miny", miny);
    nvs_get_i16(h, "midy", midy);
    nvs_get_i16(h, "maxy", maxy);
    nvs_get_i16(h, "minz", minz);
    nvs_get_i16(h, "midz", midz);
    nvs_get_i16(h, "maxz", maxz);
    nvs_get_i16(h, "minrz", minrz);
    nvs_get_i16(h, "midrz", midrz);
    nvs_get_i16(h, "maxrz", maxrz);
    nvs_close(h);
}
void saveIMUCaliOffset(int16_t *offsets)
{
    nvs_handle_t h;
    nvs_open(calinvs, NVS_READWRITE, &h);
    nvs_set_i16(h, "acclx", offsets[0]);
    nvs_set_i16(h, "accly", offsets[1]);
    nvs_set_i16(h, "acclz", offsets[2]);
    nvs_set_i16(h, "gyrox", offsets[3]);
    nvs_set_i16(h, "gyroy", offsets[4]);
    nvs_set_i16(h, "gyroz", offsets[5]);
    nvs_commit(h);
    nvs_close(h);
}
void loadIMUCaliOffset(int16_t *acclx, int16_t *accly, int16_t *acclz, int16_t *gyrox, int16_t *gyroy, int16_t *gyroz)
{
    nvs_handle_t h;
    nvs_open(calinvs, NVS_READWRITE, &h);
    nvs_get_i16(h, "acclx", acclx);
    nvs_get_i16(h, "accly", accly);
    nvs_get_i16(h, "acclz", acclz);
    nvs_get_i16(h, "gyrox", gyrox);
    nvs_get_i16(h, "gyroy", gyroy);
    nvs_get_i16(h, "gyroz", gyroz);
    nvs_close(h);
}
int getIMUEnabled()
{
    return isIMUEnabled;
}
void disableIMU()
{
    gpio_set_level(PIN_I2C_VCC, 0);
    isIMUEnabled = 0;
}
void enableIMU()
{
    if (isIMUEnabled)
        return;
    isIMUEnabled = 1;

    gpio_reset_pin(PIN_I2C_VCC);
    gpio_set_direction(PIN_I2C_VCC, GPIO_MODE_OUTPUT);
    gpio_set_level(PIN_I2C_VCC, 1);
    DELAY(10); //等上电稳定

    mpu.initialize();

    // Get Device ID
    uint8_t buffer[1];
    I2Cdev::readByte(MPU6050_ADDRESS_AD0_LOW, MPU6050_RA_WHO_AM_I, buffer);
    ESP_LOGI(TAG, "MPU6050 getDeviceID=0x%x", buffer[0]);

    int16_t acclx = 0, accly = 0, acclz = 0;
    int16_t gyrox = 0, gyroy = 0, gyroz = 0;
    loadIMUCaliOffset(&acclx, &accly, &acclz, &gyrox, &gyroy, &gyroz);

    ESP_LOGI(TAG, "Load IMU offset accl x y z: %6d %6d %6d", acclx, accly, acclz);
    ESP_LOGI(TAG, "Load IMU offset gyro x y z: %6d %6d %6d", gyrox, gyroy, gyroz);

    // // supply your own gyro offsets here, scaled for min sensitivity
    mpu.setXAccelOffset(acclx);
    mpu.setYAccelOffset(accly);
    mpu.setZAccelOffset(acclz);
    mpu.setXGyroOffset(gyrox);
    mpu.setYGyroOffset(gyroy);
    mpu.setZGyroOffset(gyroz);

    mpu.setDLPFMode(1);                                //降低采样率
    uint8_t gyroRate = mpu.getDLPFMode() == 0 ? 8 : 1; //k
    uint8_t sampleDiv = mpu.getRate();

    ESP_LOGI(TAG, "MPU6050 Sample Rate: %.2fHz", (gyroRate * 1000.0f) / (sampleDiv + 1));
}
void setIMUSensitivity(uint8_t accelRange, uint8_t gyroRange, uint8_t accelBandwidth, uint8_t gyroSampleRate)
{
    // ESP_LOGI(TAG, "setIMUSensitivity %d %d %d %d", accelRange, gyroRange, accelBandwidth, gyroSampleRate);
    mpu.setFullScaleAccelRange(accelRange);
    mpu.setFullScaleGyroRange(gyroRange);
    // 待定
    // mpu.setRate()
    // mpu.setDHPFMode()
}

//饿狗重启
void esp_task_wdt_isr_user_handler(void)
{
    reset(true);
}

// 自动校准mpu6050
void calibrateIMU()
{
    enableIMU();
    setIMUSensitivity(2, 3, 1, 1);
    mpu.setXAccelOffset(0);
    mpu.setYAccelOffset(0);
    mpu.setZAccelOffset(0);
    mpu.setXGyroOffset(0);
    mpu.setYGyroOffset(0);
    mpu.setZGyroOffset(0);

    //老外的这个校准函数有点问题，经常会卡住，所以开启任务看门狗。
    ESP_ERROR_CHECK(esp_task_wdt_add(NULL));

    // Calibration Time: generate offsets and calibrate our MPU6050
    printf("CalibrateAccel...\n");
    mpu.CalibrateAccel(6);
    printf("CalibrateGyro...\n");
    mpu.CalibrateGyro(6);

    esp_task_wdt_reset();
    //关闭看门狗
    ESP_ERROR_CHECK(esp_task_wdt_delete(NULL));

    int16_t *mpuoffset = mpu.GetActiveOffsets();
    printf("accl x,y,z offset : %6d %6d %6d\n", mpuoffset[0], mpuoffset[1], mpuoffset[2]);
    printf("gyro x,y,z offset : %6d %6d %6d\n", mpuoffset[3], mpuoffset[4], mpuoffset[5]);

    printf("saving...\n");
    saveIMUCaliOffset(mpuoffset);
    int16_t acclx = 0, accly = 0, acclz = 0;
    int16_t gyrox = 0, gyroy = 0, gyroz = 0;
    loadIMUCaliOffset(&acclx, &accly, &acclz, &gyrox, &gyroy, &gyroz);

    if (mpuoffset[0] == acclx && mpuoffset[1] == accly && mpuoffset[2] == acclz &&
        mpuoffset[3] == gyrox && mpuoffset[4] == gyroy && mpuoffset[5] == gyroz)
    {
        printf("save success!\n");
    }
    else
    {
        printf("save failed:\n");
        printf("The saved value: %6d %6d %6d %6d %d %6d is not match!\n",
               acclx, accly, acclz, gyrox, gyroy, gyroz);
    }
}

void getIMUMotionData(int16_t outData[6])
{
    mpu.getMotion6(&outData[0], &outData[1], &outData[2], &outData[3], &outData[4], &outData[5]);
}

static MyMeanFilter _mBatteryVoltage;
static int _vs[5];

static void _measureBatt()
{
    int v = getADCValueAfterCali(PIN_ADC_BATT_LEVEL) * BATT_VOLTAGE_MULTIPLY_FACTOR;
    MyMeanFilterUpdate(&_mBatteryVoltage, v);
}

static void updateMeasureBatt(uint32_t dt)
{
    static uint32_t t_notify = 0;
    static uint32_t t_measure = 0;

    t_measure += dt;
    // 5秒检测一次电池电量
    if (t_measure >= 5 * 1000)
    {
        _measureBatt();
        t_measure = 0;
    }

    t_notify += dt;
    //30秒发送一次电池电量
    if (t_notify >= 30 * 1000)
    {
        pGamepad->notifyBattLevel(getBatteryLevel());
        t_notify = 0;
    }
}

void initADCBattery()
{
    _initADCHandle();
    adc_oneshot_chan_cfg_t chanCfg = {
        .atten = DEFAULT_ADC_ATTEN_DB,
        .bitwidth = DEFAULT_ADC_BITWIDTH,
    };
    ESP_ERROR_CHECK(adc_oneshot_config_channel(adcHandle, PIN_ADC_BATT_LEVEL, &chanCfg));

    adc_cali_curve_fitting_config_t caliCfg = {
        .unit_id = DEFAULT_ADC_UNIT_ID,
        .chan = PIN_ADC_BATT_LEVEL,
        .atten = DEFAULT_ADC_ATTEN_DB,
        .bitwidth = DEFAULT_ADC_BITWIDTH,
    };
    ESP_ERROR_CHECK(adc_cali_create_scheme_curve_fitting(&caliCfg, &adcCaliHandle));

    gpio_reset_pin(PIN_CHARGING_STATE);
    gpio_set_direction(PIN_CHARGING_STATE, GPIO_MODE_INPUT);
    gpio_set_pull_mode(PIN_CHARGING_STATE, GPIO_FLOATING);
    gpio_reset_pin(PIN_CHARGING_STDBY_STATE);
    gpio_set_direction(PIN_CHARGING_STDBY_STATE, GPIO_MODE_INPUT);
    gpio_set_pull_mode(PIN_CHARGING_STDBY_STATE, GPIO_FLOATING);

    MyMeanFilterInit(&_mBatteryVoltage, _vs, sizeof(_vs));
    for (size_t i = 0; i < sizeof(_vs); i++)
    {
        _measureBatt();
    }
}

int getBatteryVoltage()
{
    return (int)round(_mBatteryVoltage.mean);
}
int getBatteryLevel()
{
    int v = clamp(getBatteryVoltage(), 3300, 4200) - 3300;
    int vv = v / (42 - 33);
    return vv;
}

//检测是否充电中。不是很准，TP4056芯片返回的值偶尔会抖动一下，不知为啥。
int isBatteryCharging()
{
    return (!gpio_get_level(PIN_CHARGING_STATE)) || (!isPowOnByPushBtn);
}

int isBatteryChargeFull()
{
    return !gpio_get_level(PIN_CHARGING_STDBY_STATE);
}

void setLEDScanning(uint8_t isScanning)
{
    _isScanning = isScanning;
}

void initLED()
{
    gpio_reset_pin(PIN_LED_1);
    gpio_reset_pin(PIN_LED_2);
    gpio_reset_pin(PIN_LED_3);
    gpio_reset_pin(PIN_LED_4);
    gpio_set_direction(PIN_LED_1, GPIO_MODE_OUTPUT);
    gpio_set_direction(PIN_LED_2, GPIO_MODE_OUTPUT);
    gpio_set_direction(PIN_LED_3, GPIO_MODE_OUTPUT);
    gpio_set_direction(PIN_LED_4, GPIO_MODE_OUTPUT);
}

void initPowSave(bool enableLightSleep)
{
    esp_pm_config_t cfg = {
        .max_freq_mhz = CONFIG_ESP_DEFAULT_CPU_FREQ_MHZ,
        .min_freq_mhz = 40,
        .light_sleep_enable = enableLightSleep};
    ESP_ERROR_CHECK(esp_pm_configure(&cfg));
}
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
void app_main(void)
{

    isPowOnByPushBtn = isBatteryConnected();
    ESP_LOGI(TAG, "------------isPowOnByPushBtn: %d------------", isPowOnByPushBtn);
    //禁用睡眠时切换gpio状态
    esp_sleep_enable_gpio_switch(false);

    if (isPowOnByPushBtn)
    {
        powOn();
        workMode();
    }
    else
    {
        disconnectBattery();
        onlyChargeMode();
    }
}

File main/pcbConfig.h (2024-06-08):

#ifndef _PCB_CONFIG_H_
#define _PCB_CONFIG_H_

#include "driver/gpio.h"
#include "esp_adc/adc_oneshot.h"

#define PIN_ROW_0 GPIO_NUM_15
#define PIN_ROW_1 GPIO_NUM_16
#define PIN_ROW_2 GPIO_NUM_17
#define PIN_ROW_3 GPIO_NUM_18

#define PIN_COL_0 GPIO_NUM_11
#define PIN_COL_1 GPIO_NUM_12
#define PIN_COL_2 GPIO_NUM_13
#define PIN_COL_3 GPIO_NUM_14

#define PIN_BTN_SELECT GPIO_NUM_0
#define PIN_SWITCH_ON_OFF GPIO_NUM_45
#define PIN_BTN_XBOX GPIO_NUM_46

#define PIN_CHARGING_STATE GPIO_NUM_39
#define PIN_CHARGING_STDBY_STATE GPIO_NUM_40

#define PIN_I2C_VCC GPIO_NUM_3
#define PIN_I2C_SCL GPIO_NUM_41
#define PIN_I2C_SDA GPIO_NUM_42

#define PIN_LED_1 GPIO_NUM_21
#define PIN_LED_2 GPIO_NUM_47
#define PIN_LED_3 GPIO_NUM_48
#define PIN_LED_4 GPIO_NUM_38

#define PIN_MOTOR_L GPIO_NUM_9
#define PIN_MOTOR_R GPIO_NUM_10
#define LEDC_MOTOR_SPEED_MODE LEDC_LOW_SPEED_MODE
#define LEDC_MOTOR_L_TIMER LEDC_TIMER_1
#define LEDC_MOTOR_R_TIMER LEDC_TIMER_2
#define LEDC_MOTOR_L_CHANNEL LEDC_CHANNEL_0
#define LEDC_MOTOR_R_CHANNEL LEDC_CHANNEL_1
#define LEDC_MOTOR_FRQ_DEFAULT 10 //越大振感越弱

#define PIN_ADC_LT ADC_CHANNEL_0         //GPIO_NUM_1
#define PIN_ADC_RT ADC_CHANNEL_1         //GPIO_NUM_2
#define PIN_ADC_X ADC_CHANNEL_3          //GPIO_NUM_4
#define PIN_ADC_Y ADC_CHANNEL_4          //GPIO_NUM_5
#define PIN_ADC_Z ADC_CHANNEL_6          //GPIO_NUM_7
#define PIN_ADC_RZ ADC_CHANNEL_5         //GPIO_NUM_6
#define PIN_ADC_BATT_LEVEL ADC_CHANNEL_7 //GPIO_NUM_8

#define BATT_VOLTAGE_MULTIPLY_FACTOR 2 //分压测量电压

#pragma pack(push, 1)
typedef struct
{
    uint8_t A : 1;
    uint8_t B : 1;
    uint8_t X : 1;
    uint8_t Y : 1;
    uint8_t Up : 1;
    uint8_t Right : 1;
    uint8_t Down : 1;
    uint8_t Left : 1;
    uint8_t LS : 1;
    uint8_t RS : 1;
    uint8_t LB : 1;
    uint8_t RB : 1;
    uint8_t Start : 1;
    uint8_t ext1 : 1;
    uint8_t ext2 : 1;
    uint8_t ext3 : 1;
} KeyMatrix_t;

typedef enum
{
    GAMEPAD_TYPE_XBOX = 0,
    GAMEPAD_TYPE_SWITCH_PRO = 1,
    GAMEPAD_TYPE_DS = 3, //跳过2，2是电量低指示灯
} Enum_Gamepad_Type;

#pragma pack(pop)

#ifdef __cplusplus
extern "C"
{
#endif

    //0~100
    extern void setMotorLevel(uint16_t lMotor, uint16_t rMotor);
    extern void setMotorFreq(uint16_t lFreq, uint16_t rFreq);
    extern void getMotorLevel(uint16_t *lMotor, uint16_t *rMotor);
    extern void enableIMU();
    extern void disableIMU();
    /**
     * accel range
     * 0 = +/- 2g
     * 1 = +/- 4g
     * 2 = +/- 8g
     * 3 = +/- 16g
     * gyro range
     * 0 = +/- 250 degrees/sec
     * 1 = +/- 500 degrees/sec
     * 2 = +/- 1000 degrees/sec
     * 3 = +/- 2000 degrees/sec
     * bandwidth 0 1
     * samplerate 0 1
    */
    extern void setIMUSensitivity(uint8_t accelRange, uint8_t gyroRange, uint8_t accelBandwidth, uint8_t gyroSampleRate);
    extern void calibrateIMU();
    //return accel offset int16_t * 3 gyro offset int16_t * 3
    extern int16_t *getIMUCalibrateOffset();
    extern void getIMUMotionData(int16_t outData[6]);
    extern int getIMUEnabled();
    //3300~4200 mv
    extern int getBatteryVoltage();
    //0~100
    extern int getBatteryLevel();
    extern int isBatteryCharging();
    extern int isBatteryChargeFull();
    extern void setLEDScanning(uint8_t isScanning);

#ifdef __cplusplus
}
#endif

#endif

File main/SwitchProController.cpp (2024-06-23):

/**
 * 参考：
 * https://github.com/dekuNukem/Nintendo_Switch_Reverse_Engineering.git
 * https://github.com/mumumusuc/libjoycon.git
 * https://github.com/EasyConNS/BlueCon-esp32.git
 * SDL-SDL2\src\joystick\hidapi\SDL_hidapi_switch.c
*/
/**
 * steam 有点问题，如果先开steam再连手柄会出现手柄没振动功能；
 * 先连手柄再开steam就没问题。
*/
#include "SwitchProController.h"
#include "NimBLEDevice.h"
#include "ble_uuid.h"
#include "helper.h"
#include "math.h"

#define VID_SIG 2 //(1=Bluetooth SIG, 2=USB SIG)
#define VID 0x057E
#define PID 0x2009
#define PID_VER 0x0101

#define HID_RPT_ID_INPUT_STD 0x21           //Standard input reports used for subcommand replies.
#define HID_RPT_ID_INPUT_NFC_FW_UPDATE 0x23 //NFC/IR MCU FW update input report.
#define HID_RPT_ID_INPUT_FULL 0x30          //input reports with IMU data instead of subcommand replies.Pushes current state @120Hz
#define HID_RPT_ID_INPUT_NFC_MCU 0x31       //Pushes large packets with standard input report + NFC/IR MCU data input report.
#define HID_RPT_ID_INPUT_UNKNOWN1 0x32      //Sends standard input reports.
#define HID_RPT_ID_INPUT_UNKNOWN2 0x33      //Sends standard input reports.
#define HID_RPT_ID_INPUT 0x3F

#define HID_RPT_ID_OUTPUT_RUMBLE_SUBCMD 0x01
#define HID_RPT_ID_OUTPUT_RUMBLE 0x10
#define HID_RPT_ID_OUTPUT_REQ_NFC_OR_RUMBLE 0x11
#define HID_RPT_ID_OUTPUT_UNKNOWN 0x12

#define SUB_CMD_GET_STATE 0x00
#define SUB_CMD_BT_MANUAL_PAIRING 0x01
#define SUB_CMD_REQ_DEVICE_INFO 0x02
#define SUB_CMD_SET_INPUT_RPT_MODE 0x03
#define SUB_CMD_TRIGGER_BTNS_TIME_ELAPSED 0x04
#define SUB_CMD_GET_PAGE_LIST_STATE 0x05
#define SUB_CMD_SET_HCI_STATE 0x06
#define SUB_CMD_RESET_PAIRING_INFO 0x07
#define SUB_CMD_SET_LOW_POWER_SHIPPING_STATE 0x08
#define SUB_CMD_SET_SPI_FLASH_READ 0x10
#define SUB_CMD_SET_SPI_FLASH_WRITE 0x11
#define SUB_CMD_SET_SPI_SECTOR_ERASE 0x12
#define SUB_CMD_SET_RESET_NFC 0x20
#define SUB_CMD_SET_SET_NFC_CONFIG 0x21
#define SUB_CMD_SET_SET_NFC_STATE 0x22
#define SUB_CMD_SET_PLAYER_LED 0x30
#define SUB_CMD_GET_PLAYER_LED 0x31
#define SUB_CMD_SET_HOME_LED 0x38
#define SUB_CMD_ENABLE_IMU 0x40
#define SUB_CMD_SET_IMU_SENSITIVITY 0x41
#define SUB_CMD_WRITE_IMU_REG 0x42
#define SUB_CMD_READ_IMU_REG 0x43
#define SUB_CMD_ENABLE_VIBRATION 0x48
#define SUB_CMD_GET_REGULATED_VOLTAGE 0x50

#define INPUT_REPORT_FULL_SIZE 48
#define INPUT_REPORT_STAND_SIZE 48

#define RPT_MODE_NFC_IR_CAM 0x0  //Active polling for NFC/IR camera data.
#define RPT_MODE_NFC_IR_MCU 0x1  //Active polling mode for NFC/IR MCU configuration data
#define RPT_MODE_NFC_IR_DATA 0x2 //Active polling mode for NFC/IR data and configuration
#define RPT_MODE_IR_CAM 0x3      //Active polling mode for IR camera data.
#define RPT_MODE_STANDARD 0x30   //Standard full mode. Pushes current state @60Hz
#define RPT_MODE_NFC_IR 0x31     //NFC/IR mode. Pushes large packets @60Hz
#define RPT_MODE_33 0x33         // ?
#define RPT_MODE_35 0x35         // ?
#define RPT_MODE_SIMPLE_HID 0x3F //Simple HID mode. Pushes updates with every button press

#define DELAY(x) vTaskDelay((x) / portTICK_PERIOD_MS)

static const char *TAG = "swpro";
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

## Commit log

2024-06-15 加上材料及价格清单
2024-06-17 修复关机充电电量一直显示0
2024-06-17 禁用睡眠时切换gpio状态
2024-06-18 仅充电模式的代码有点小问题修复一下
2024-06-18 充电太慢了电路这样改一下吧
2024-06-19 tp4056是10个Y3.8
2024-06-23 cpu正常频率改到80Hz减少耗电；改一下刷新方式
2024-07-06 矩阵键盘加点防抖试试水
2024-07-09 降低mpu6050采样率
2024-09-21 保存个默认sdkconfig
2024-09-24 写上idf需要的版本
2024-11-23 忘了说摇杆位置有点偏需要自己实际测量调整一下PCB
2024-12-06 修复同时按下左摇杆跟A键会触发start键
